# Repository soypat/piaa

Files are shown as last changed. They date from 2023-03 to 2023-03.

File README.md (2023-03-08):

# piaa
PIAA, inspired by the [CIAA project](https://github.com/ciaa/Hardware).

The PIAA is a open source [printed cicuit board](https://en.wikipedia.org/wiki/Printed_circuit_board) design for use in industrial settings where [electromagnetic interference](https://en.wikipedia.org/wiki/Electromagnetic_interference) is of great concern. The on board processor is intended to be the RP2040 contained in the [Raspberry Pi Pico](https://www.raspberrypi.com/products/raspberry-pi-pico/) package

Features:
- All I/O except for GPIO header come with extensive EMI protection.
- Wide temperature range components.
- 1 RS485 peripheral using MAX3072E.
- 6 Digital outputs with PWM capabilities.
- 4 digital inputs.
- Powered be 6-24V input.
- 8 additional GPIO on header with SPI, I2C, UART, PWM, PIO capabilities. This header is connected to GPIO0 through GPIO7.
- Regulated 3.3V and 5V outputs.
- Grounded padding on sides of Proant wifi/bluetooth antenna to potentially increase antenna gain (not tested).

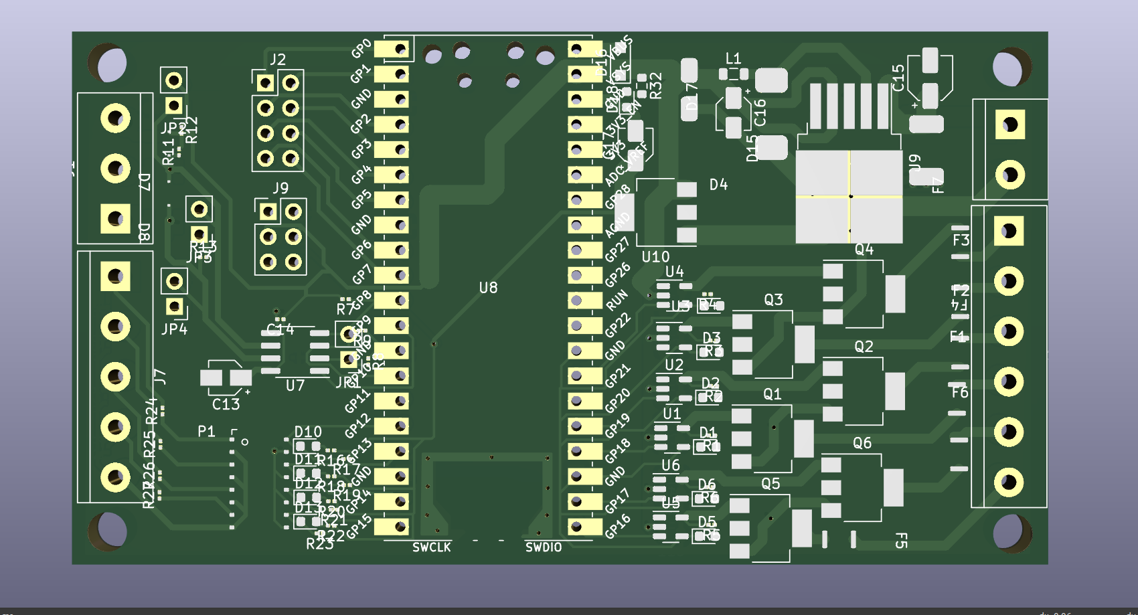
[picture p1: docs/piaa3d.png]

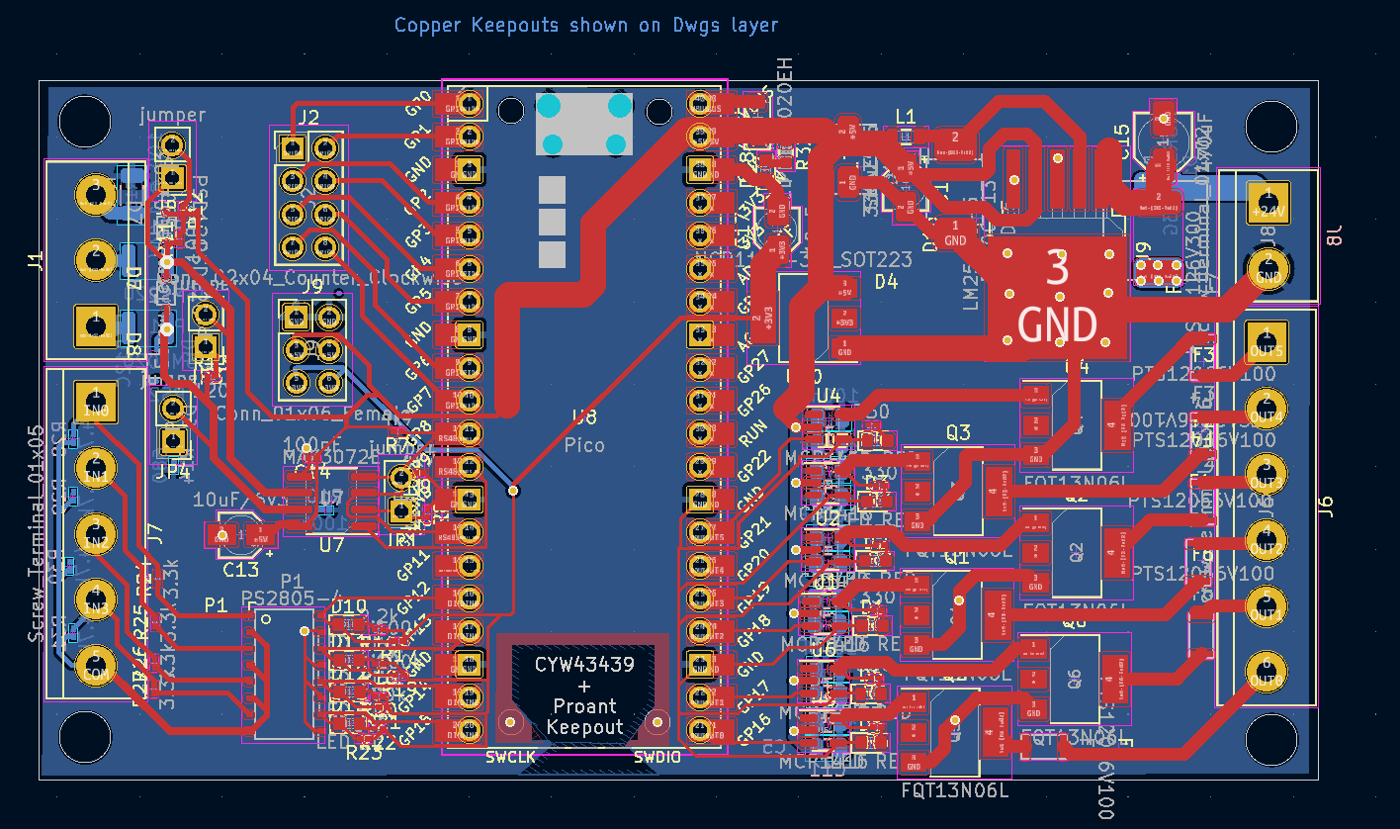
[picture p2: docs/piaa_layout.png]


# Kicad: Project setup
This project was made entirely with Kicad.

Download external dependencies with:

```sh
git submodule update --init
```

## Further setup
I'd believe the project should be set automatically since I've taken care to include all libraries as "Project" libraries, not "Global". 
In any case, if that fails you may follow the steps detailed here to setup any symbol, footprint and 3D model libraries that may be needed
to work or visualize the PIAA.

1. After initializing git submodules with external symbol and footprint libraries (with `git submodule update --init`) follow the symbol installation instructions at [this link](https://github.com/ncarandini/KiCad-RP-Pico/blob/main/Install%20instructions.md) and use the footprint in the folder [RP-Pico Libraries](./submodules/KiCad-RP-Pico/RP-Pico Libraries).

2. Setup `piaalib` symbol and footprint libraries. They are located under [design/lib/piaalib](./design/lib/piaalib).
The steps to adding these libraries are the same as with the RP-Pico libraries.

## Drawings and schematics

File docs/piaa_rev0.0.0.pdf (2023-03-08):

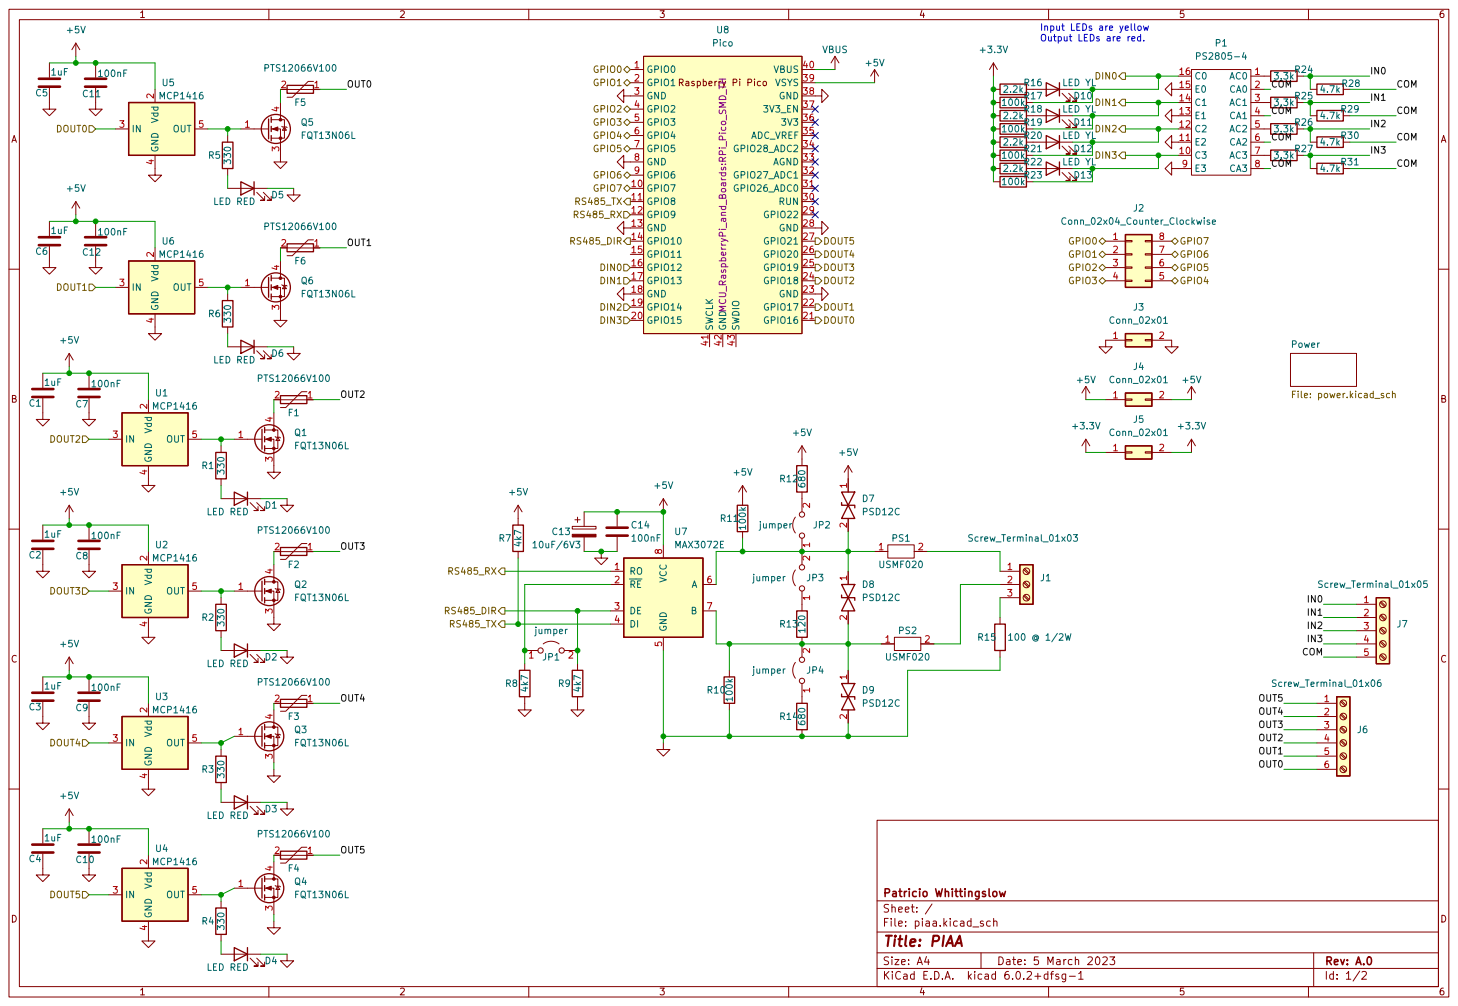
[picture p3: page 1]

Input LEDs are yellow
Output LEDs are red.
COM

File: piaa.kicad_sch Sheet: / Patricio Whittingslow

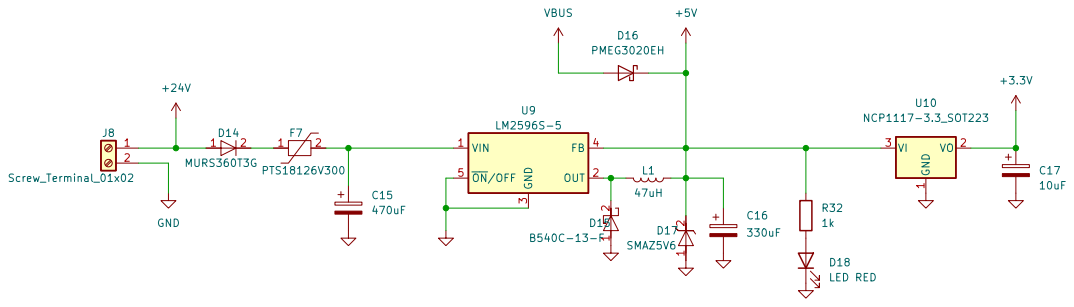
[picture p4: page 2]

File: power.kicad_sch Sheet: /Power/ Patricio Whittingslow

Id: 2/2 Title: PIAA (power)

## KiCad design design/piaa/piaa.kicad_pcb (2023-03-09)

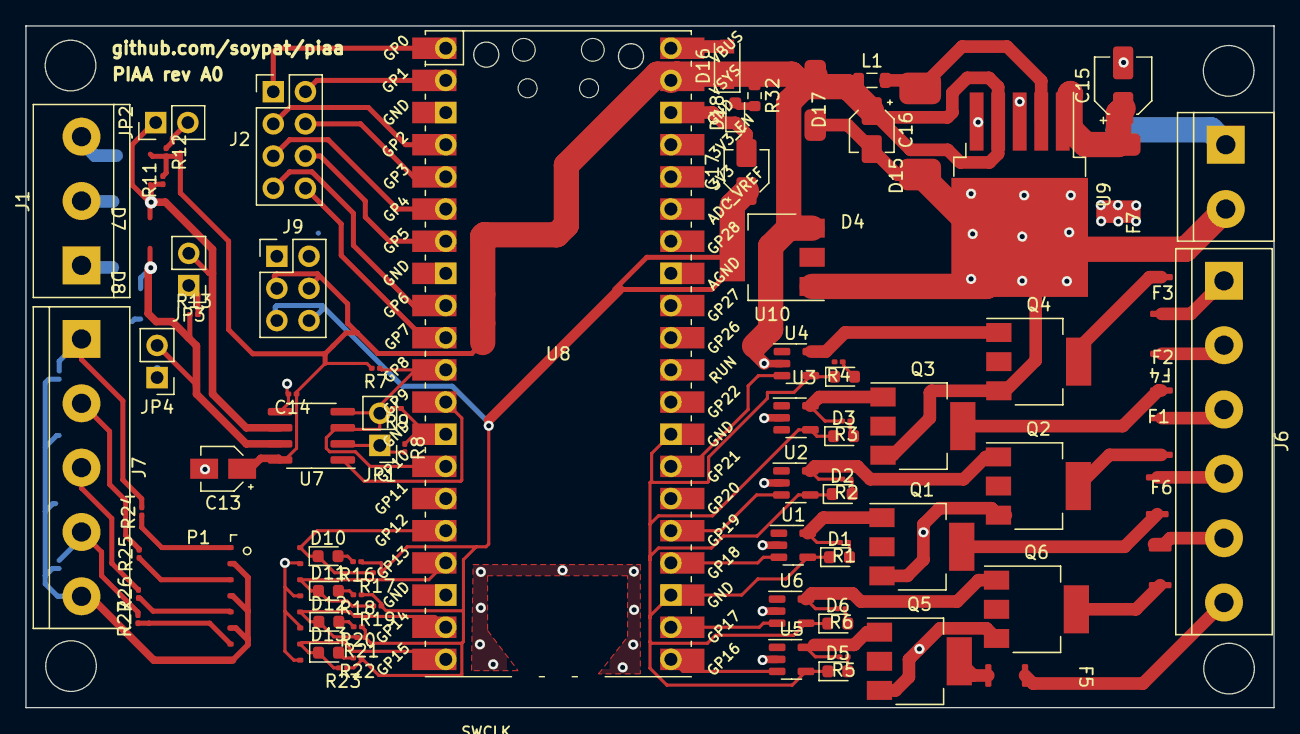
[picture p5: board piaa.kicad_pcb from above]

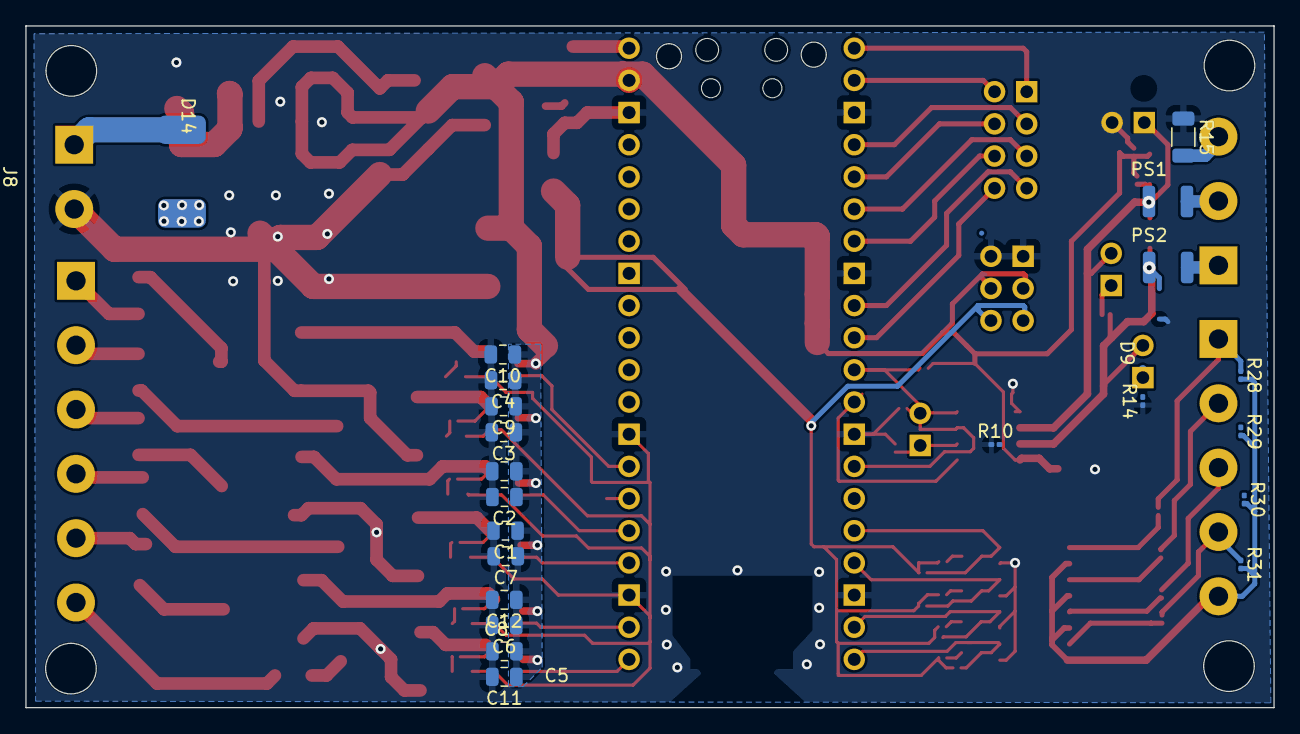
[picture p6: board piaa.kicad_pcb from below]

Board: 2 copper layers, 98.6 x 53.8 mm, 104 parts (23 on the bottom side), 76 nets.

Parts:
C1, C2, C3, C4, C5, C6: 1uF; C_0805_2012Metric
C7, C8, C9, C10, C11, C12: 100nF; C_0805_2012Metric
C13: 10uF/6V3; CP_Elec_3x5.3
C14: 100nF; C_0201_0603Metric
C15: 470uF; CP_Elec_4x3
C16: 330uF; CP_Elec_3x5.4
C17: 10uF; CP_Elec_3x5.4
D1, D2, D3, D4, D5, D6, D18: LED RED; LED_0603_1608Metric
D7, D8, D9: PSD12C; SOD-323
D10, D11, D12, D13: LED YL; LED_0603_1608Metric
D14: MURS360T3G
D15: B540C-13-F
D16: PMEG3020EH; D_SOD-123F
D17: SMAZ5V6
F1, F2, F3, F4, F5, F6: PTS12066V100
F7: PTS18126V300
J1: Screw_Terminal_01x03; TerminalBlock_bornier-3_P5.08mm
J2: Conn_02x04_Counter_Clockwise; PinHeader_2x04_P2.54mm_Vertical
J6: Screw_Terminal_01x06; TerminalBlock_bornier-6_P5.08mm
J7: Screw_Terminal_01x05; TerminalBlock_bornier-5_P5.08mm
J8: Screw_Terminal_01x02; TerminalBlock_bornier-2_P5.08mm
J9: Conn_01x06_Female; PinHeader_2x03_P2.54mm_Vertical
JP1, JP2, JP3, JP4: jumper; PinHeader_1x02_P2.54mm_Vertical
L1: 47uH; L_0805_2012Metric
P1: PS2805-4; SSOP-16_0.5x0.4mm_pitch1.27mm
PS1, PS2: USMF020
Q1, Q2, Q3, Q4, Q5, Q6: FQT13N06L; SOT-223
R1, R2, R3, R4, R5, R6: 330; R_0201_0603Metric
R7, R8, R9: 4k7; R_0201_0603Metric
R10, R11, R17, R19, R21, R23: 100k; R_0201_0603Metric
R12, R14: 680; R_0201_0603Metric
R13: 120; R_0201_0603Metric
R15: 100 @ 1/2W; R_1206_3216Metric
R16, R18, R20, R22: 2.2k; R_0201_0603Metric
R24, R25, R26, R27: 3.3k; R_0201_0603Metric
R28, R29, R30, R31: 4.7k; R_0201_0603Metric
R32: 1k; R_0603_1608Metric
U1, U2, U3, U4, U5, U6: MCP1416; SOT-23-5
U7: MAX3072E; SOIC-8_3.9x4.9mm_P1.27mm
U8: Pico; RPi_Pico_SMD_TH
U9: LM2596S-5; TO-263-5_TabPin3
U10: NCP1117-3.3_SOT223; SOT-223-3_TabPin2

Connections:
+3V3: C17.1, J9.5, J9.6, R16.1, R17.1, R18.1, R19.1, R20.1, R21.1, R22.1, R23.1, U10.2 (VO)
+5V: C1.1, C2.1, C3.1, C4.1, C5.1, C6.1, C7.1, C8.1, C9.1, C10.1, C11.1, C12.1, C13.1, C14.1, C16.1, D7.1, D16.1 (K), D17.2, J9.3, J9.4, L1.1, R7.2, R11.2, R12.2, R32.1, U1.2 (Vdd), U2.2 (Vdd), U3.2 (Vdd), U4.2 (Vdd), U5.2 (Vdd), U6.2 (Vdd), U7.8 (VCC), U8.39 (VSYS), U9.4 (FB), U10.3 (VI)
+24V: D14.1, J8.1
/COM: J7.5, P1.2 (CA0), P1.4 (CA1), P1.6 (CA2), P1.8 (CA3), R28.2, R29.2, R30.2, R31.2
/DIN0: D10.1 (K), P1.16 (C0), R17.2, U8.16 (GPIO12)
/DIN1: D11.1 (K), P1.14 (C1), R19.2, U8.17 (GPIO13)
/DIN2: D12.1 (K), P1.12 (C2), R21.2, U8.19 (GPIO14)
/DIN3: D13.1 (K), P1.10 (C3), R23.2, U8.20 (GPIO15)
/DOUT0: U5.3 (IN), U8.21 (GPIO16)
/DOUT1: U6.3 (IN), U8.22 (GPIO17)
/DOUT2: U1.3 (IN), U8.24 (GPIO18)
/DOUT3: U2.3 (IN), U8.25 (GPIO19)
/DOUT4: U3.3 (IN), U8.26 (GPIO20)
/DOUT5: U4.3 (IN), U8.27 (GPIO21)
/GPIO0: J2.1, U8.1 (GPIO0)
/GPIO1: J2.2, U8.2 (GPIO1)
/GPIO2: J2.3, U8.4 (GPIO2)
/GPIO3: J2.4, U8.5 (GPIO3)
/GPIO4: J2.5, U8.6 (GPIO4)
/GPIO5: J2.6, U8.7 (GPIO5)
/GPIO6: J2.7, U8.9 (GPIO6)
/GPIO7: J2.8, U8.10 (GPIO7)
/IN0: J7.1, R24.2, R28.1
/IN1: J7.2, R25.2, R29.1
/IN2: J7.3, R26.2, R30.1
/IN3: J7.4, R27.2, R31.1
/OUT0: F5.1, J6.6
/OUT1: F6.1, J6.5
/OUT2: F1.1, J6.4
/OUT3: F2.1, J6.3
/OUT4: F3.1, J6.2
/OUT5: F4.1, J6.1
/RS485_DIR: JP1.2 (B), R9.2, U7.3 (DE), U8.14 (GPIO10)
/RS485_RX: U7.1 (RO), U8.12 (GPIO9)
/RS485_TX: R7.1, U7.4 (DI), U8.11 (GPIO8)
GND: C1.2, C2.2, C3.2, C4.2, C5.2, C6.2, C7.2, C8.2, C9.2, C10.2, C11.2, C12.2, C13.2, C14.2, C15.2, C16.2, C17.2, D1.1 (K), D2.1 (K), D3.1 (K), D4.1 (K), D5.1 (K), D6.1 (K), D9.2, D15.1, D17.1, D18.1 (K), J8.2, J9.1, J9.2, P1.9 (E3), P1.11 (E2), P1.13 (E1), P1.15 (E0), Q1.3 (S), Q2.3 (S), Q3.3 (S), Q4.3 (S), Q5.3 (S), Q6.3 (S), R8.1, R9.1, R10.1, R14.1, R15.1, U1.4 (GND), U2.4 (GND), U3.4 (GND), U4.4 (GND), U5.4 (GND), U6.4 (GND), U7.5 (GND), U8.3 (GND), U8.8 (GND), U8.13 (GND), U8.18 (GND), U8.23 (GND), U8.28 (GND), U8.38 (GND), U9.3 (GND), U9.5 (~ON/OFF), U10.1 (GND)
unnamed: C15.1, F7.2, U9.1 (VIN)
unnamed: D1.2 (A), R1.1
unnamed: D2.2 (A), R2.1
unnamed: D3.2 (A), R3.1
unnamed: D4.2 (A), R4.1
unnamed: D5.2 (A), R5.1
unnamed: D6.2 (A), R6.1
unnamed: D7.2, D8.1, JP2.1 (A), JP3.2 (B), PS1.1, R11.1, U7.6 (A)
unnamed: D8.2, D9.1, JP4.2 (B), PS2.1, R10.2, R13.1, U7.7 (B)
unnamed: D10.2 (A), R16.2
unnamed: D11.2 (A), R18.2
unnamed: D12.2 (A), R20.2
unnamed: D13.2 (A), R22.2
unnamed: D14.2, F7.1
unnamed: D15.2, L1.2, U9.2 (OUT)
unnamed: D18.2 (A), R32.2
unnamed: F1.2, Q1.4 (D)
unnamed: F2.2, Q2.4 (D)
unnamed: F3.2, Q3.4 (D)
unnamed: F4.2, Q4.4 (D)
unnamed: F5.2, Q5.4 (D)
unnamed: F6.2, Q6.4 (D)
unnamed: J1.3, R15.2
unnamed: JP1.1 (A), R8.2, U7.2 (~RE)
unnamed: JP2.2 (B), R12.1
unnamed: JP3.1 (A), R13.2
unnamed: JP4.1 (A), R14.2
unnamed: P1.1 (AC0), R24.1
unnamed: P1.3 (AC1), R25.1
unnamed: P1.5 (AC2), R26.1
unnamed: P1.7 (AC3), R27.1
unnamed: J1.2, PS1.2
unnamed: J1.1, PS2.2
unnamed: Q1.1 (G), R1.2, U1.5 (OUT)
unnamed: Q2.1 (G), R2.2, U2.5 (OUT)
unnamed: Q3.1 (G), R3.2, U3.5 (OUT)
unnamed: Q4.1 (G), R4.2, U4.5 (OUT)
unnamed: Q5.1 (G), R5.2, U5.5 (OUT)
unnamed: Q6.1 (G), R6.2, U6.5 (OUT)
VBUS: D16.2 (A), U8.40 (VBUS)

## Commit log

2023-03-05 fix symbols, begin layout
    [piaa.kicad_pcb, piaa.kicad_sch, power.kicad_sch]
2023-03-05 update to pcb drawing
    [piaa.kicad_pcb, piaa.kicad_sch, power.kicad_sch]
2023-03-05 finalized drawing
    [piaa.kicad_pcb]
2023-03-05 add antenna keepout and padding
    [piaa.kicad_pcb]
2023-03-05 add antenna padding disclaimer
2023-03-05 specify project was made with kicad
2023-03-08 updates to schematic
    [piaa.kicad_sch, power.kicad_sch]
2023-03-09 fix header and bornier size
    [piaa.kicad_pcb, piaa.kicad_sch, power.kicad_sch]
2023-03-09 thicker 3v3 line
    [piaa.kicad_pcb]
